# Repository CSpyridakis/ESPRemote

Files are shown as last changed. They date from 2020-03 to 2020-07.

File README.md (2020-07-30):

# ESPRemote
### VER 1.1

This repository is a fork of [Almidi's version of ESPRemote](https://github.com/Almidi/ESPRemote), a simple WiFI remote controller using the ESP8266 SoC.

The main difference between his implementation and this fork is about the limit of the input power supply voltage. In his repo, he uses an _[AP2112K](https://www.google.gr/url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)_ LDO voltage regulator that has a 6.5V Vin limit, to power it from USB chargers. 

Personally, I have all over in my place 12V power supplies to power led strips, for this reason, it would be a nice touch if I could power it directly from there without the need for an external power supply. So in this fork, the [NCP1117](https://www.onsemi.com/pub/Collateral/NCP1117-D.PDF) or [AMS1117](http://www.advanced-monolithic.com/pdf/ds1117.pdf) voltage regulator is used.

Please check out his [repo](https://github.com/Almidi/ESPRemote) if you want to use the battery/5v dc version, learn more about the beginning version or details about the firmware.

## PCB
### Schematic
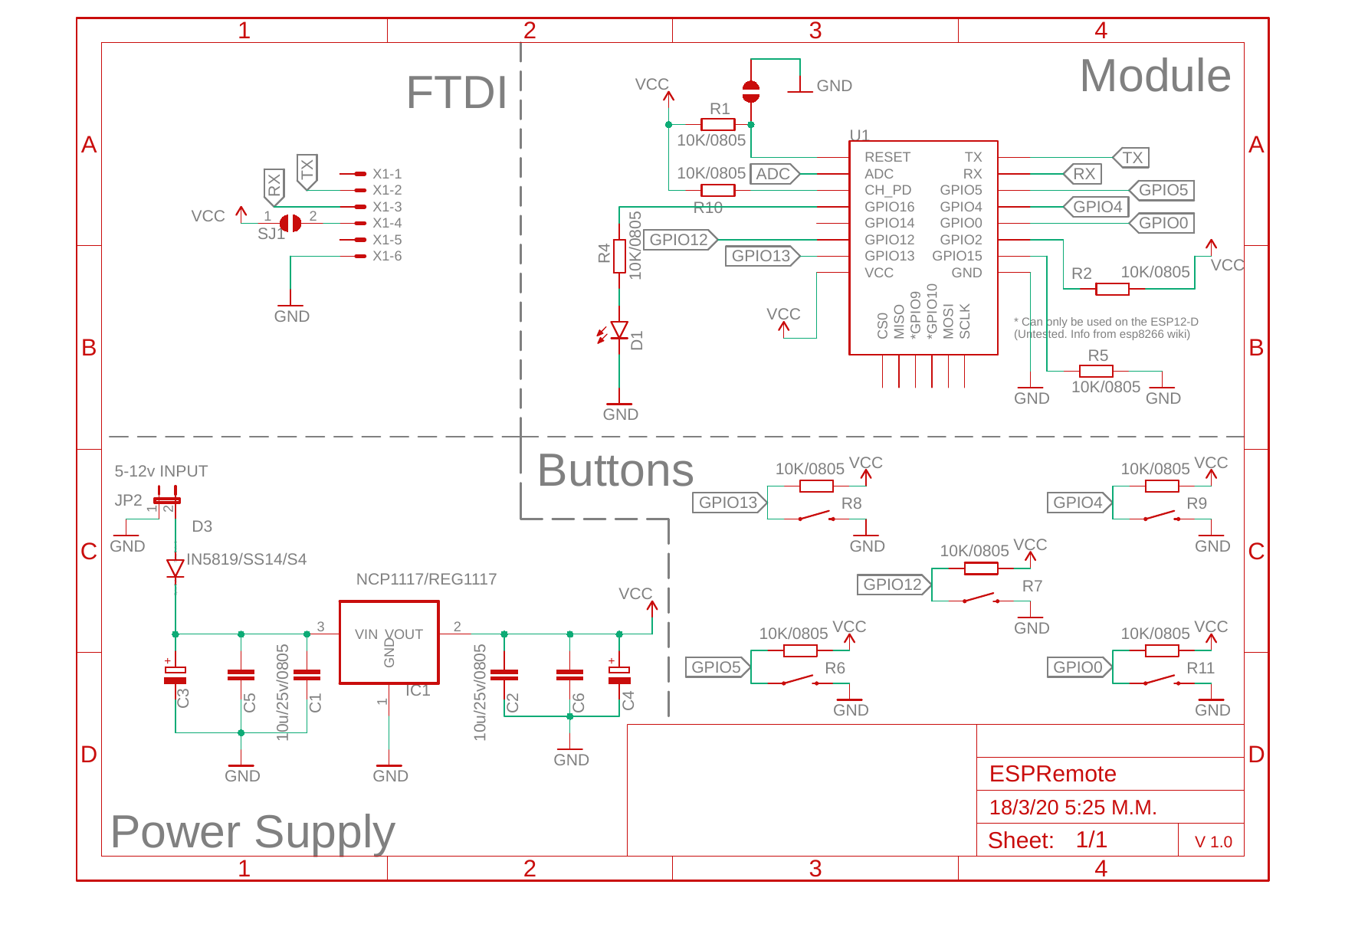
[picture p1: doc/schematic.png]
PCB 3D Model


#### Note: C3, C4, C5 and C6 are optional !!!

### Assembly
| No  | Component | Quantity |
|:---:|:---:|:---:|
| 1.  | ESP8266 - 12e/f | 1 | 
| 2.  | 10KΩ 0805 smd resistors | 9 | 
| 3.  | SMD-SWITCH-6.2MM | 5 |
| 4.  |  IN5819 or SS14 or S4 Diode  | 1 |
| 5.  | NCP1117 or REG1117 Regulator | 1 |
| 6.  | 10uF 25v 0805 smd capasitors | 2 |
| 7.  | 0603 smd led | 1 |
| 8.  |  0805 smd resistor for led <sup>1</sup>  | 1 |

<sup>1</sup> The resistor value depends on the color of the led you would choose to use.

### Top
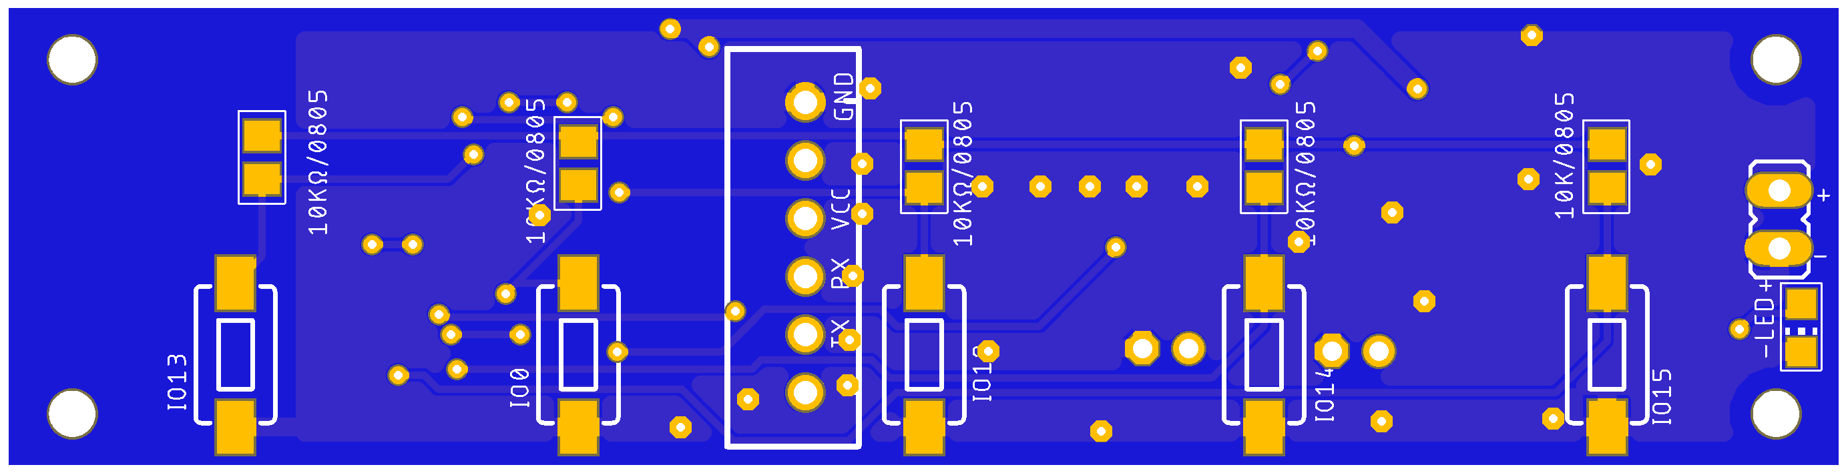
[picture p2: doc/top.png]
Top


### Bottom
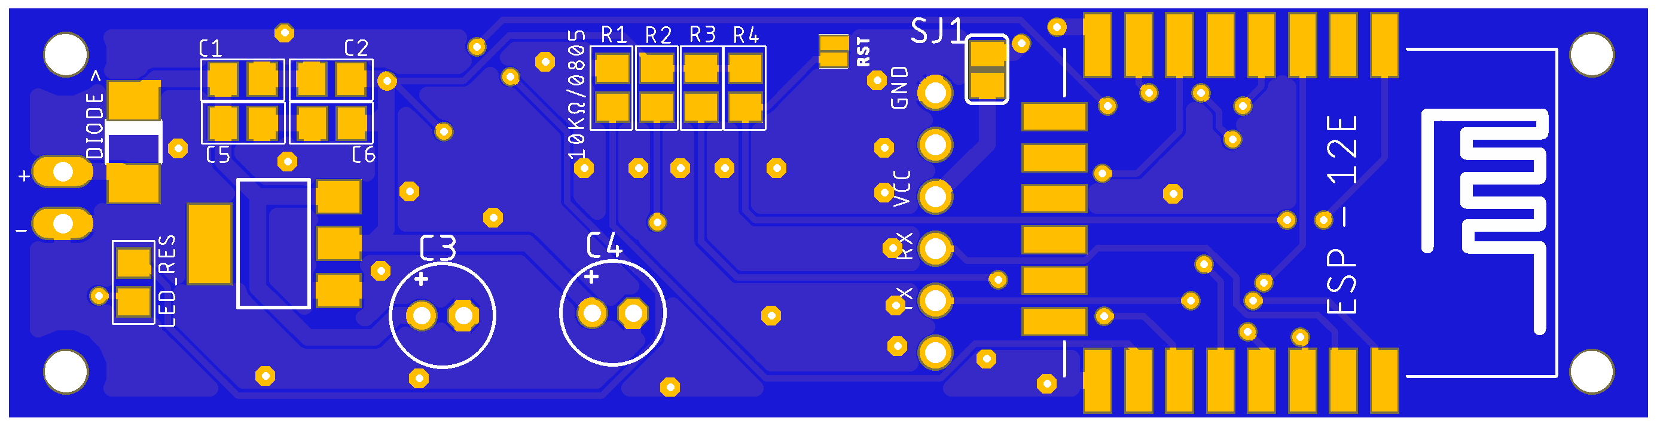
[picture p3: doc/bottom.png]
Bottom


## I/O

| Usage | Pin |
|---|---|
| Button 1 | GPIO5  |
| Button 2 | GPIO4  |
| Button 3 | GPIO12 |
| Button 4 | GPIO0  |
| Button 5 | GPIO13 |
| Status Led | GPIO16 |

## Enclosure 
I also use [Almidi's](https://github.com/Almidi/ESPRemote) enclosure for this version.

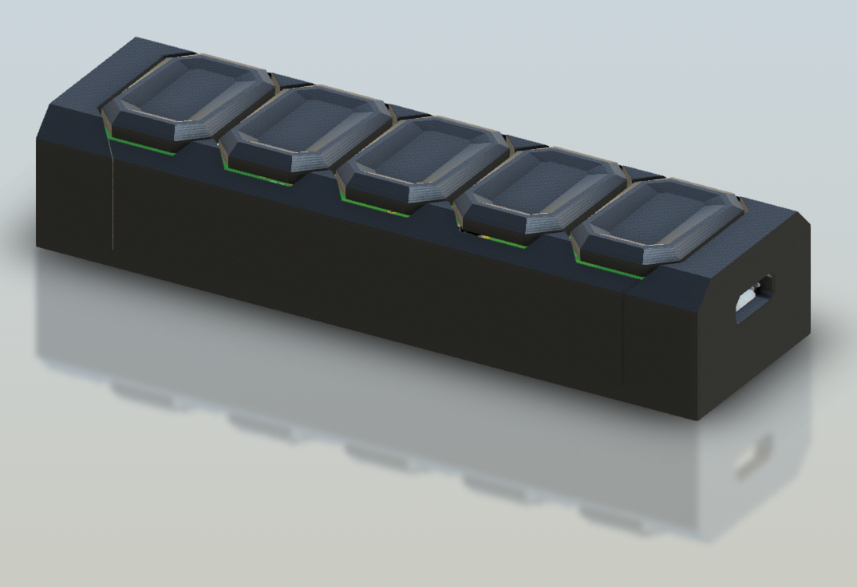
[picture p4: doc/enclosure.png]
3D Model


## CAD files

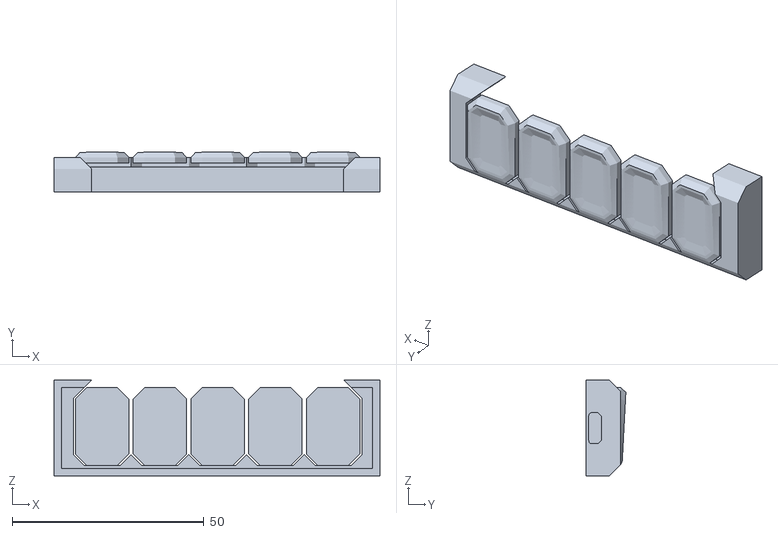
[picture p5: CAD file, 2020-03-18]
enclosure/Body.stl
85.0 x 10.4 x 25.0

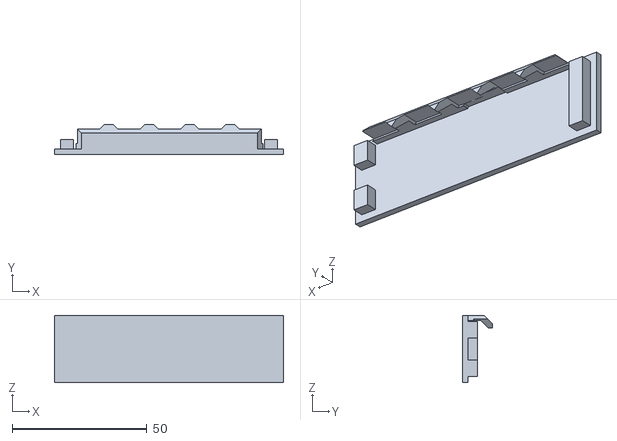
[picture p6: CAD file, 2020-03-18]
enclosure/Base.stl
85.0 x 11.0 x 25.0

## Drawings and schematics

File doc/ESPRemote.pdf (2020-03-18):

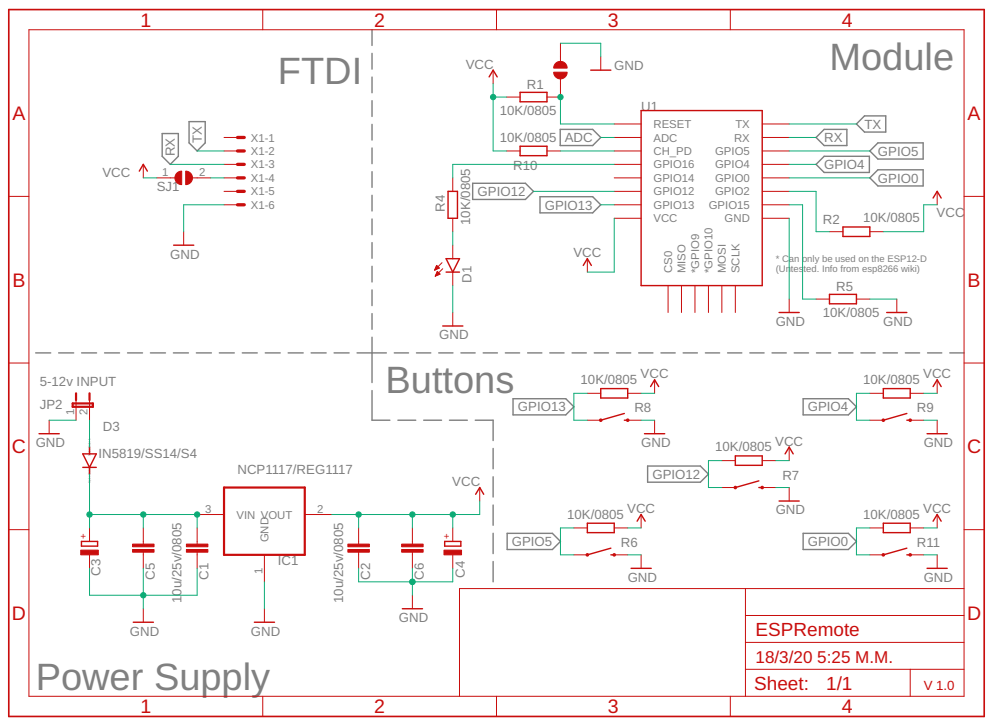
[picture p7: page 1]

* Can only be used on the ESP12-D
(Untested. Info from esp8266 wiki)

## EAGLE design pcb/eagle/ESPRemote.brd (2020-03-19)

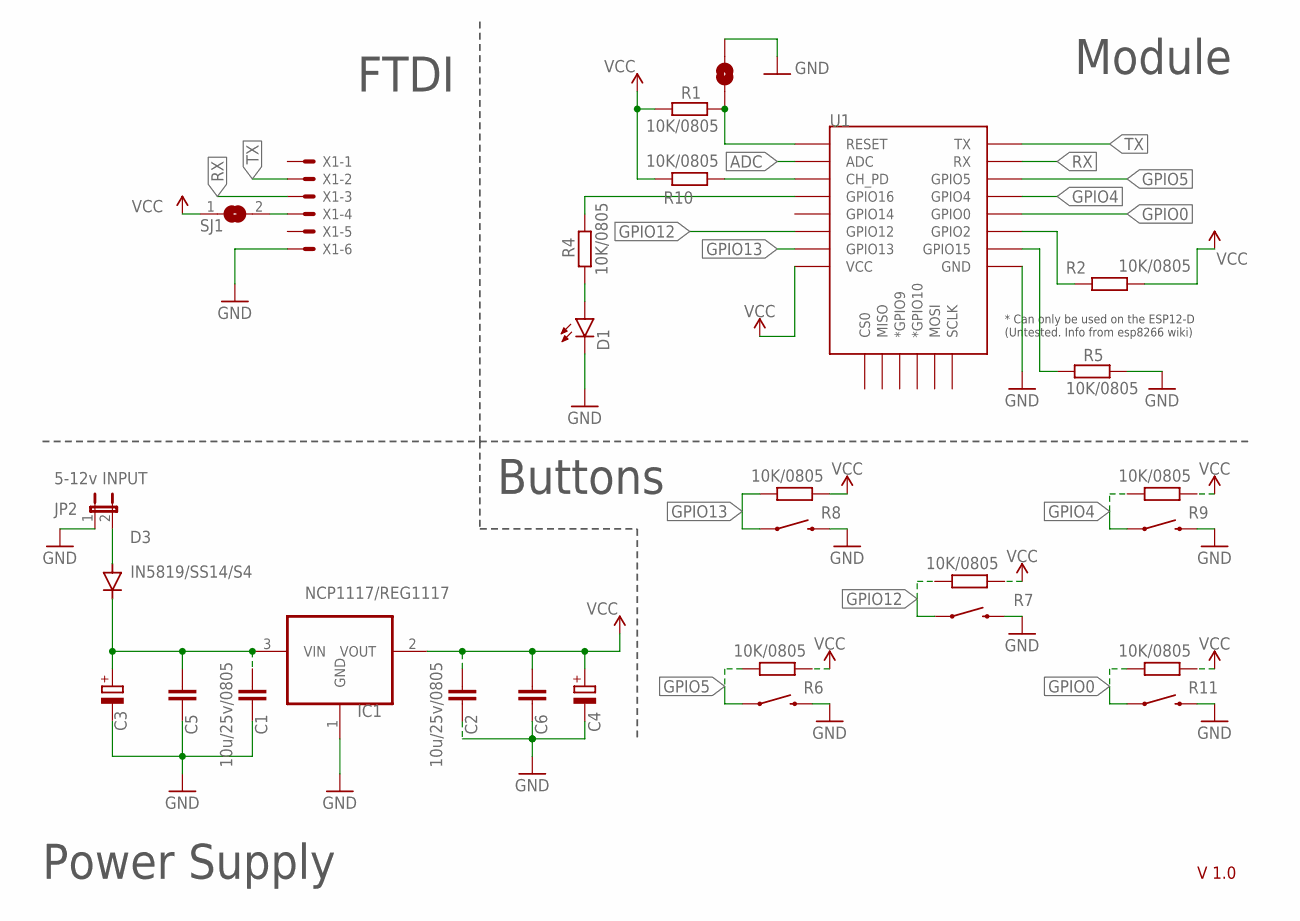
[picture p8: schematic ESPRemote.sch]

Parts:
C1, C2, C5, C6: 10u/25v/0805; C0805
C3, C4: CPOL-EUE2-5; E2-5
D1: BLUE; CHIP-LED0805
D3: IN5819/SS14/S4; DO-214AC
IC1: NCP1117/REG1117; SOT223
JP1: RST; SMT-JUMPER_2_NO_NO-SILK
JP2: 5-12v INPUT; JP1
R1, R2, R4, R5, R6, R7, R8, R9, R10, R11: 10K/0805; R0805
S0, S1, S2, S3, S4: SMD-SWITCH-6.2MM; TACTILE_SWITCH_SMD_6.0X3.5MM
SJ1: SJ
U1: ESP12ESMD; ESP12E-SMD
X1: JST-XH-06-PIN-ROUND-PAD; JST-XH-06-PACKAGE-ROUND-PAD

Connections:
ADC: U1.ADC
GND: C1.1, C2.1, C3.-, C4.-, C5.1, C6.1, D1.C, IC1.1 (GND), JP1.2, JP2.1, R5.2, S0.2, S1.2, S2.2, S3.2, S4.2, U1.GND, X1.6
GPIO0: R11.1, S4.1, U1.GPIO0
GPIO4: R9.1, S3.1, U1.GPIO4
GPIO5: R6.1, S2.1, U1.GPIO5
GPIO12: R7.1, S1.1, U1.GPIO12
GPIO13: R8.1, S0.1, U1.GPIO13
unnamed: C1.2, C3.+, C5.2, D3.C, IC1.3 (VIN)
unnamed: JP1.1, R1.2, U1.RESET
unnamed: D3.A, JP2.2
unnamed: R10.2, U1.CH_PD
unnamed: R2.1, U1.GPIO2
unnamed: SJ1.2, X1.4
unnamed: R5.1, U1.GPIO15
unnamed: R4.2, U1.GPIO16
unnamed: D1.A, R4.1
RX: U1.RXD0 (RX), X1.3
TX: U1.TXD0 (TX), X1.2
VCC: C2.2, C4.+, C6.2, IC1.2 (VOUT), R1.1, R2.2, R6.2, R7.2, R8.2, R9.2, R10.1, R11.2, SJ1.1, U1.VCC

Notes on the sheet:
Buttons
Module
FTDI
Power Supply
V 1.0

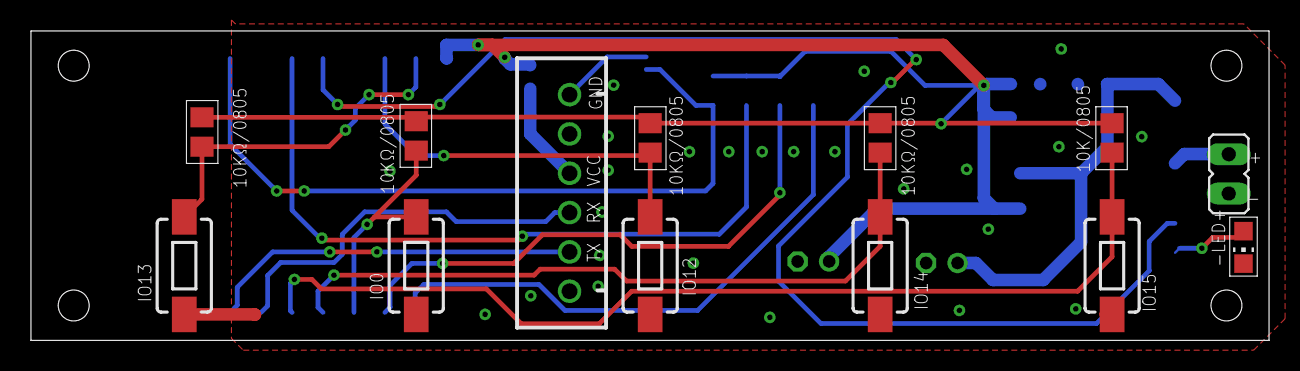
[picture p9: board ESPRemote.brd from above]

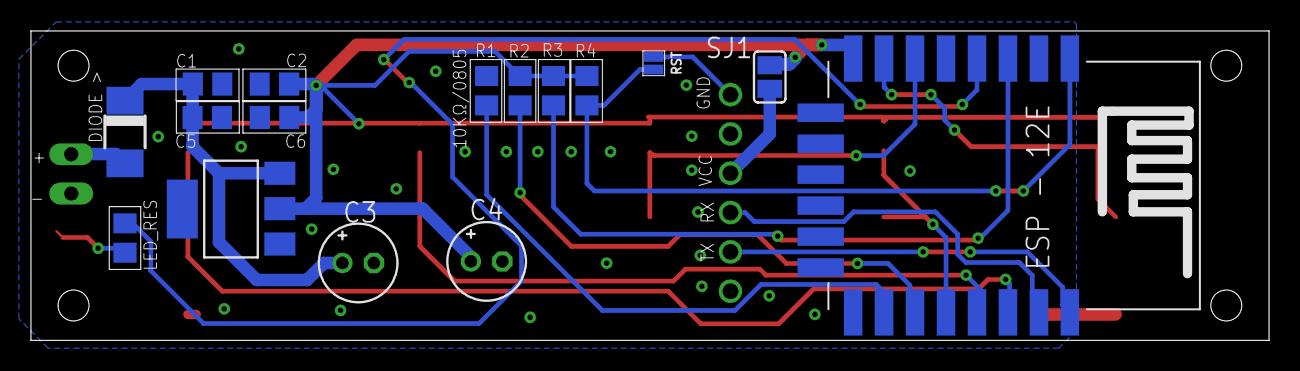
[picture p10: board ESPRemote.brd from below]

Board: 2 copper layers, 80.0 x 20.0 mm, 29 parts (16 on the bottom side), 18 nets.

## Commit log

2020-03-18 Ver.1.1 updated with 12V regulator
    [BOM.csv, Base.stl, Body.stl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]
2020-03-18 Led's trace width updated
    [ESPRemote.brd]
2020-03-19 Fix airwires
    [ESPRemote.brd]
2020-03-20 Crop pcb images

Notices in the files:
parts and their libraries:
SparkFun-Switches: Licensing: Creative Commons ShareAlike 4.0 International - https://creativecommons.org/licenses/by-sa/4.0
